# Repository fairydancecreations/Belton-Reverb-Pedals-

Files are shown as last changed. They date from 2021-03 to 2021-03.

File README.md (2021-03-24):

# Belton-Reverb-Pedals-
2 schims and pcb +gerbers for a BH2 and a BH3 belton brick reverbs. note the tone stack before the gain. seems stupid right ? have faith and try it with modulations. the BJT boost after is to give it level. both pcbs and circuits have parts to be included and changed to make overdrive versions. simply add the 2 soft clipping diodes . pick your fave and change the gain pot from 100k to 500k . this is a loud pedal so take the vol pot down to 50k if your speakers are in danger.

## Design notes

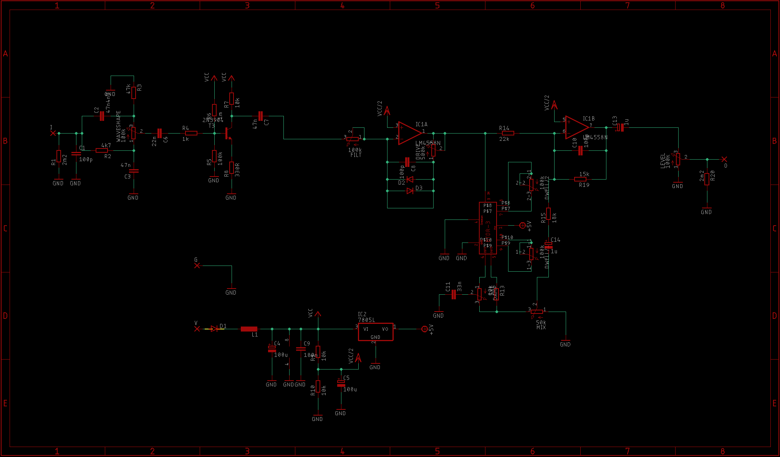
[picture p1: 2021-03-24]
BH3 reverb schim.png

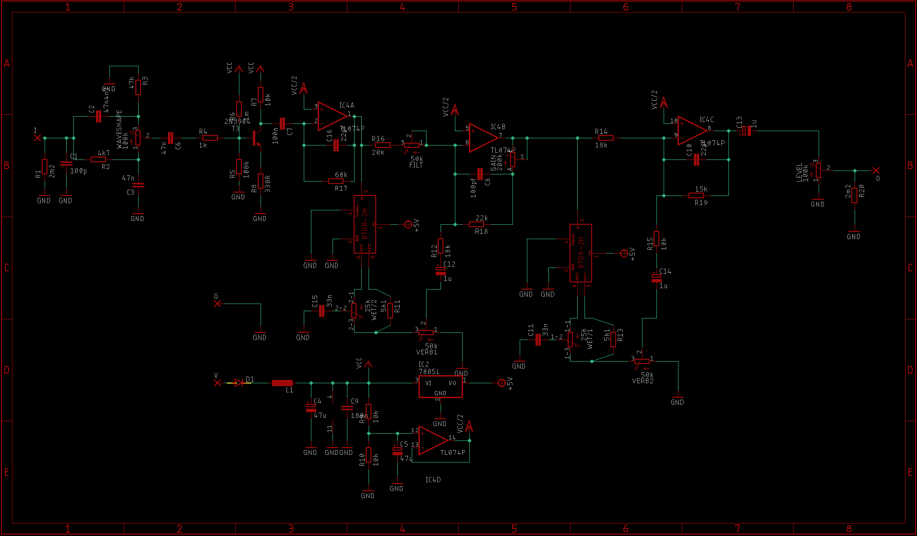
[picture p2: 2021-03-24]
BH2 reverb schim.png

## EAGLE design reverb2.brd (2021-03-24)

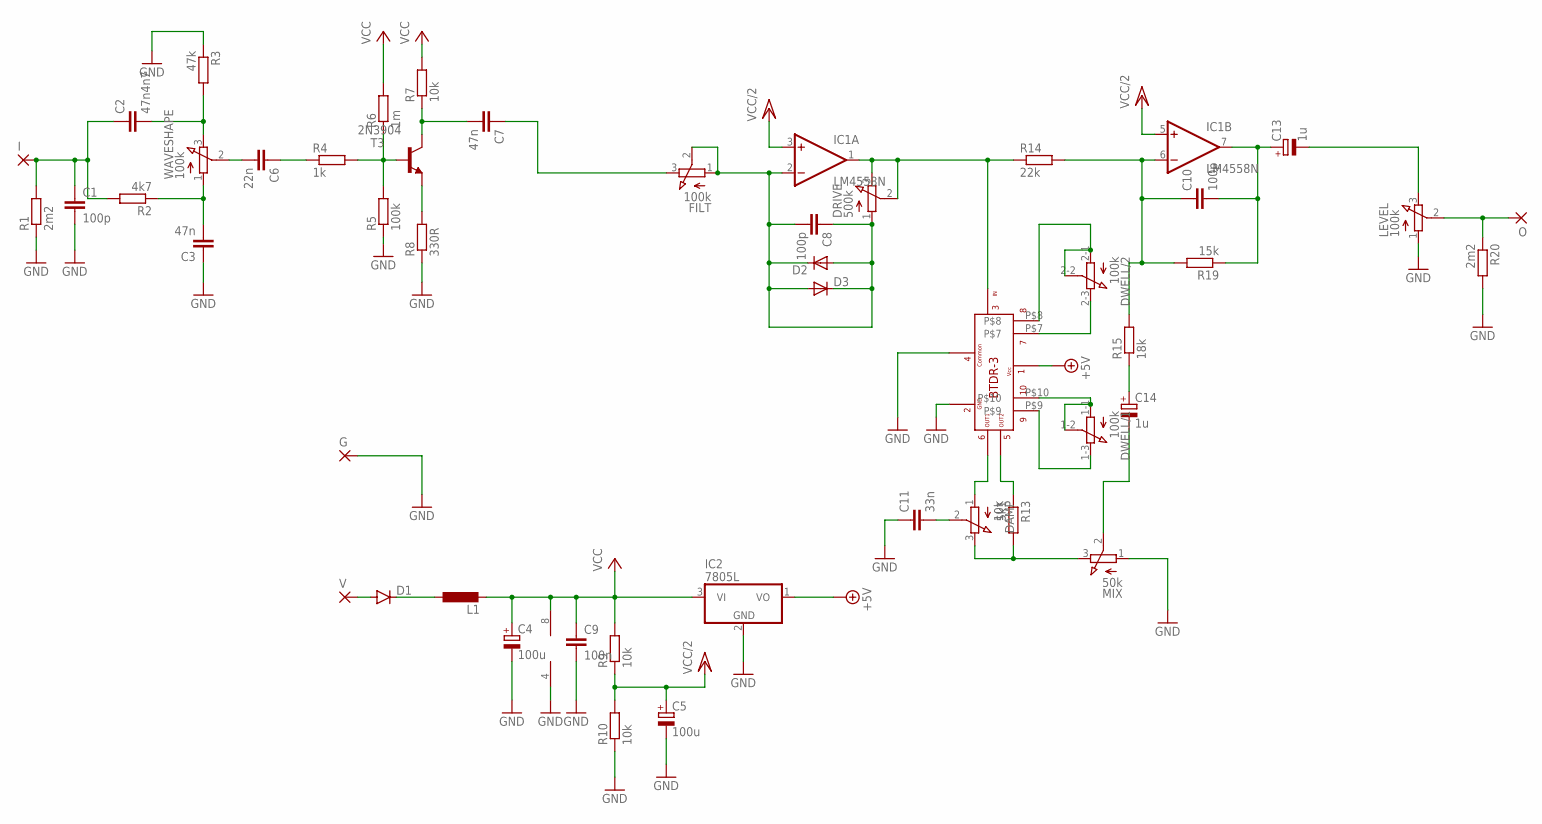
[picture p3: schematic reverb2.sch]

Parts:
C1, C8, C10: 100p; S5MMHEXCAP
C2: 47n4n7; S5MMHEXCAP
C3, C7: 47n; S5MMHEXCAP
C4, C5: 100u; E2,5-7
C6: 22n; S5MMHEXCAP
C9: 100n; S5MMHEXCAP
C11: 33n; S5MMHEXCAP
C13, C14: 1u; E2-4
D1: 1N4148DO35-7; DO35-7
D2, D3: SMALL_DIODEDO35-7; DO35-7
DAMP: 10k; 3RP/1610N
DRIVE: 500k; 3RP/1610N
DWELL: 100k; 3RP/1610G
FILT: 100k; 3RP/1610N
G: WIREPAD1,6/0,9; 1,6/0,9
I: WIREPAD1,6/0,9; 1,6/0,9
IC1: LM4558N; DIL08
IC2: 7805L; TO92
L1: L-EU0204/7; 0204/7
LEVEL: 100k; 3RP/1610N
MIX: 50k; 3RP/1610N
O: WIREPAD1,6/0,9; 1,6/0,9
R1, R20: 2m2; 0207/7
R2: 4k7; 0207/7
R3: 47k; 0207/7
R4: 1k; 0207/7
R5: 100k; 0207/7
R6: 1m; 0207/7
R7, R9, R10: 10k; 0207/7
R8: 330R; 0207/7
R13: 5k1; 0207/7
R14: 22k; 0207/7
R15: 18k; 0207/7
R19: 15k; 0207/7
T3: 2N3904; TO92
U$2: BTDR-3; BTDR3
V: WIREPAD1,6/0,9; 1,6/0,9
WAVESHAPE: 100k; 3RP/1610N

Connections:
+5V: IC2.1 (VO), U$2.P$1
GND: C1.2, C3.1, C4.-, C5.-, C9.2, C11.1, G.1, IC1.4 (V-), IC2.2 (GND), LEVEL.1 (A), MIX.1 (A), R1.1, R3.1, R5.1, R8.1, R10.1, R20.2, U$2.P$2, U$2.P$4
unnamed: R4.2, R5.2, R6.1, T3.2 (B)
unnamed: C7.2, R7.1, T3.1 (C)
unnamed: DWELL.2-3 (E), U$2.P$7
unnamed: R13.1, U$2.P$5
unnamed: DAMP.1 (A), U$2.P$6
unnamed: C7.1, FILT.3 (E)
unnamed: DAMP.3 (E), MIX.3 (E), R13.2
unnamed: D1.C, L1.1
unnamed: C2.2, R3.2, WAVESHAPE.3 (E)
unnamed: C13.-, LEVEL.3 (E)
unnamed: C14.-, MIX.2 (S)
unnamed: C11.2, DAMP.2 (S)
unnamed: C10.1, IC1.6 (-IN), R14.2, R15.2, R19.2
unnamed: C14.+, R15.1
unnamed: C6.1, R4.1
unnamed: C8.1, C8.2, D2.A, D2.C, D3.A, D3.C, DRIVE.1 (A), FILT.1 (A), FILT.2 (S), IC1.2 (-IN)
unnamed: C3.2, R2.1, WAVESHAPE.1 (A)
unnamed: R8.2, T3.3 (E)
unnamed: C1.1, C2.1, I.1, R1.2, R2.2
unnamed: C6.2, WAVESHAPE.2 (S)
unnamed: LEVEL.2 (S), O.1, R20.1
unnamed: D1.A, V.1
unnamed: DRIVE.2 (S), DRIVE.3 (E), IC1.1 (OUT), R14.1, U$2.P$3
unnamed: C10.2, C13.+, IC1.7 (OUT), R19.1
unnamed: DWELL.2-1 (A), DWELL.2-2 (S), U$2.P$8
unnamed: DWELL.1-3 (E), U$2.P$9
unnamed: DWELL.1-1 (A), DWELL.1-2 (S), U$2.P$10
VCC: C4.+, C9.1, IC1.8 (V+), IC2.3 (VI), L1.2, R6.2, R7.2, R9.2
VCC/2: C5.+, IC1.3 (+IN), IC1.5 (+IN), R9.1, R10.2

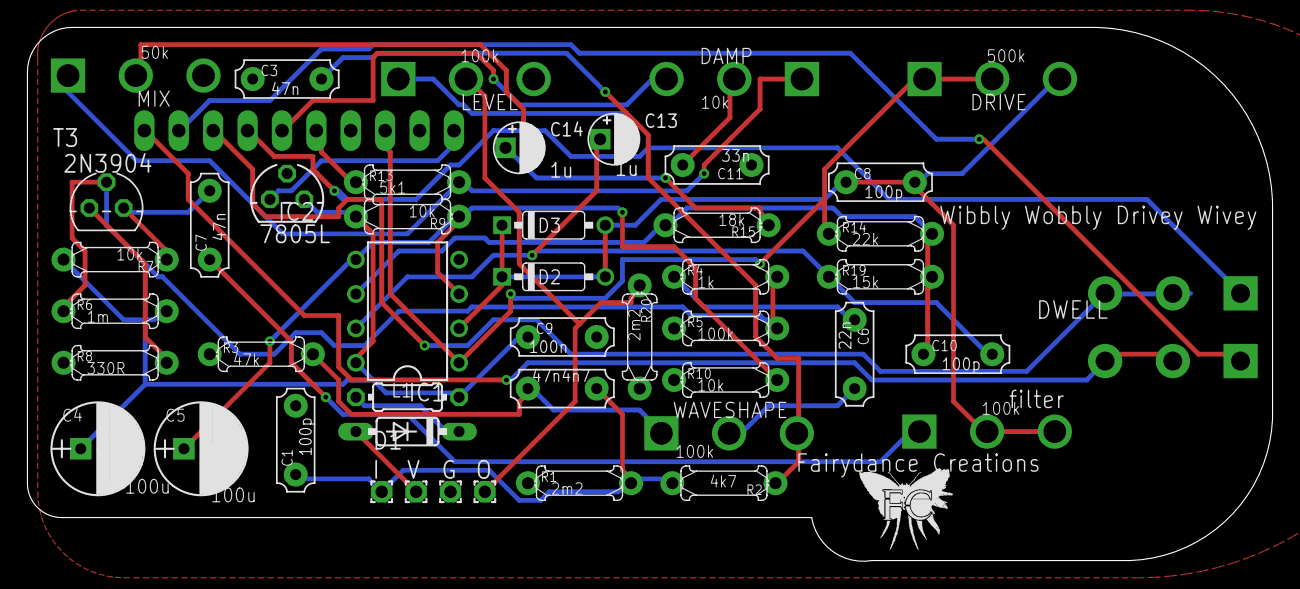
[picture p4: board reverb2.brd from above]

Board: 2 copper layers, 91.9 x 39.4 mm, 47 parts (1 on the bottom side), 31 nets.
